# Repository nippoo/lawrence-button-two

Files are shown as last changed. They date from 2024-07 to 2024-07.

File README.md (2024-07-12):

# Lawrence Button Two

This repository contains the STL files, KiCad design and Gerber files, and Arduino code used in building the Lawrence Button Two. Unlike the first button (a custom STM32-based audio player) the electronics are a simpler, through-hole-only design.

button_back

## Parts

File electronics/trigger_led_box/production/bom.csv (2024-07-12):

Designator | Footprint | Quantity | Value | LCSC Part #
A1, A2 | Arduino_Nano | 2 | Arduino_Nano_v3.x
C1, C2 | C_Rect_L7.0mm_W2.5mm_P5.00mm | 2 | 100nF
C3 | C_Rect_L7.0mm_W2.5mm_P5.00mm | 1 | 10uF
C4, C5, C6 | CP_Radial_D10.0mm_P5.00mm | 3 | 1000uF
D1 | LED_D3.0mm_Horizontal_O1.27mm_Z10.0mm | 1 | LED
J1 | Lumberg-0105-05 | 1 | Lumberg 0105-05
J2, J3 | TerminalBlock_Phoenix_PT-1,5-2-5.0-H_1x02_P5.00mm_Horizontal | 2 | Screw_Terminal_01x02
J4 | Jack_XLR_Neutrik_NC5MAH_Horizontal | 1 | NC5MAH
J6 | Jack_XLR_Neutrik_NC5FAH_Horizontal | 1 | NC5FAH
J7 | TerminalBlock_Phoenix_PT-1,5-9-5.0-H_1x09_P5.00mm_Horizontal | 1 | Screw_Terminal_01x09
PS1 | Converter_DCDC_Murata_MEE1SxxxxSC_THT | 1 | MEE1S0505SC
R1, R2 | R_Axial_DIN0207_L6.3mm_D2.5mm_P10.16mm_Horizontal | 2 | 220R | C22962
R3 | R_Axial_DIN0207_L6.3mm_D2.5mm_P10.16mm_Horizontal | 1 | 4k7
R4, R5, R6, R7, R8 | R_Axial_DIN0207_L6.3mm_D2.5mm_P10.16mm_Horizontal | 5 | 470R
U1 | DIP-8_W7.62mm | 1 | MAX485E
U2 | DIP-8_W7.62mm | 1 | 6N137

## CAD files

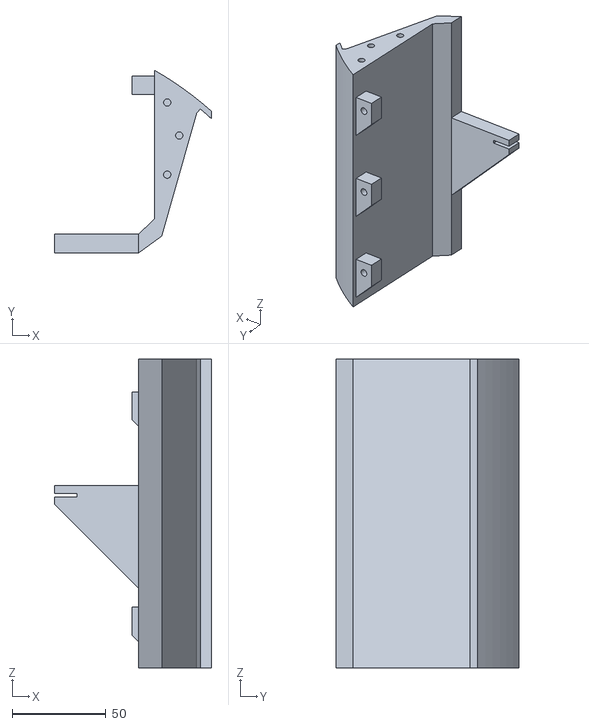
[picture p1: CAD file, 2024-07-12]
cad/left-wing.stl
83.9 x 97.5 x 165.0

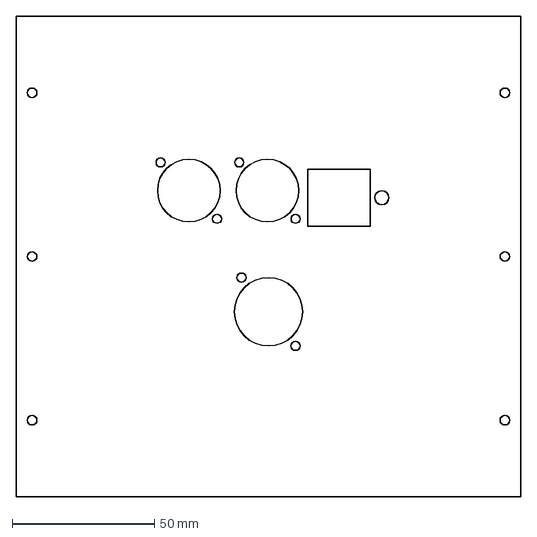
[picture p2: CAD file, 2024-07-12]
cad/frontplate.dxf
177.4 x 169.0 mm

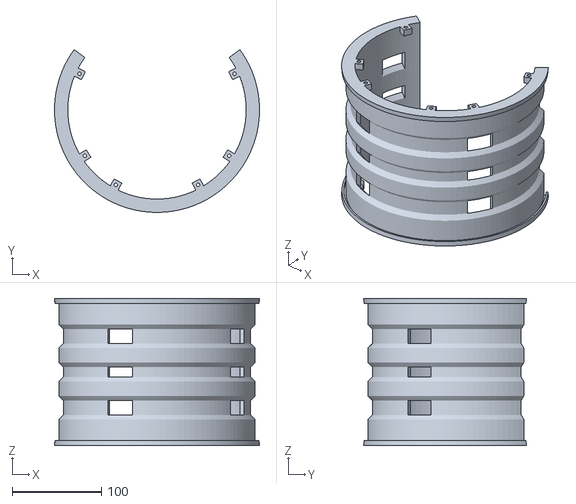
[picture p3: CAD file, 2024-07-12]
cad/middle.stl
229.9 x 182.5 x 165.0

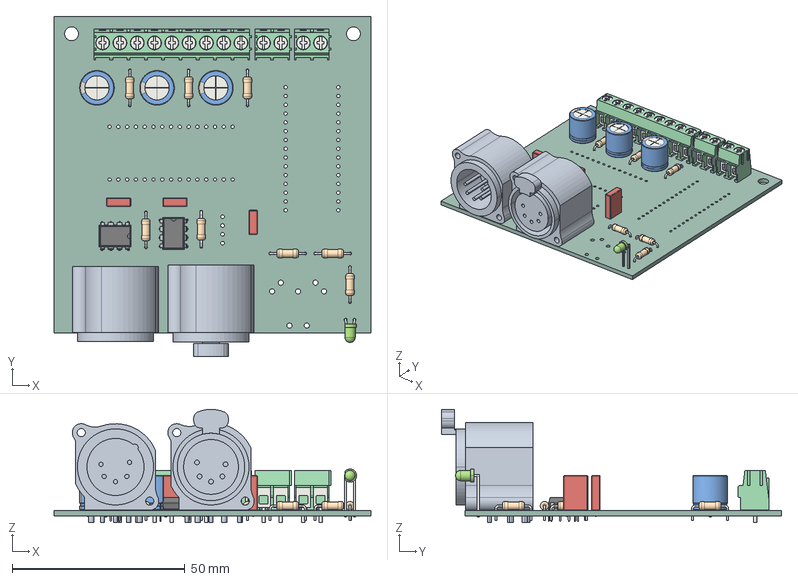
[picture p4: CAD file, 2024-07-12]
cad/trigger_led_box.step
91.5 x 98.3 x 32.7 mm
TerminalBlock_Phoenix_PT_15_2_50_H_1x02_P500mm_Horizontal x 2
R_Axial_DIN0207_L63mm_D25mm_P1016mm_Horizontal x 8
C_Rect_L70mm_W25mm_P500mm x 3
DIP-8_W7.62mm x 2
CP_Radial_D100mm_P500mm x 3
LED_D3.0mm_Horizontal_O1.27mm_Z10.0mm
NC5FAH
NC5MAH
TerminalBlock_Phoenix_PT_15_9_50_H_1x09_P500mm_Horizontal
_autosave-trigger_led_box_PCB

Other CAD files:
cad/right-wing.stl

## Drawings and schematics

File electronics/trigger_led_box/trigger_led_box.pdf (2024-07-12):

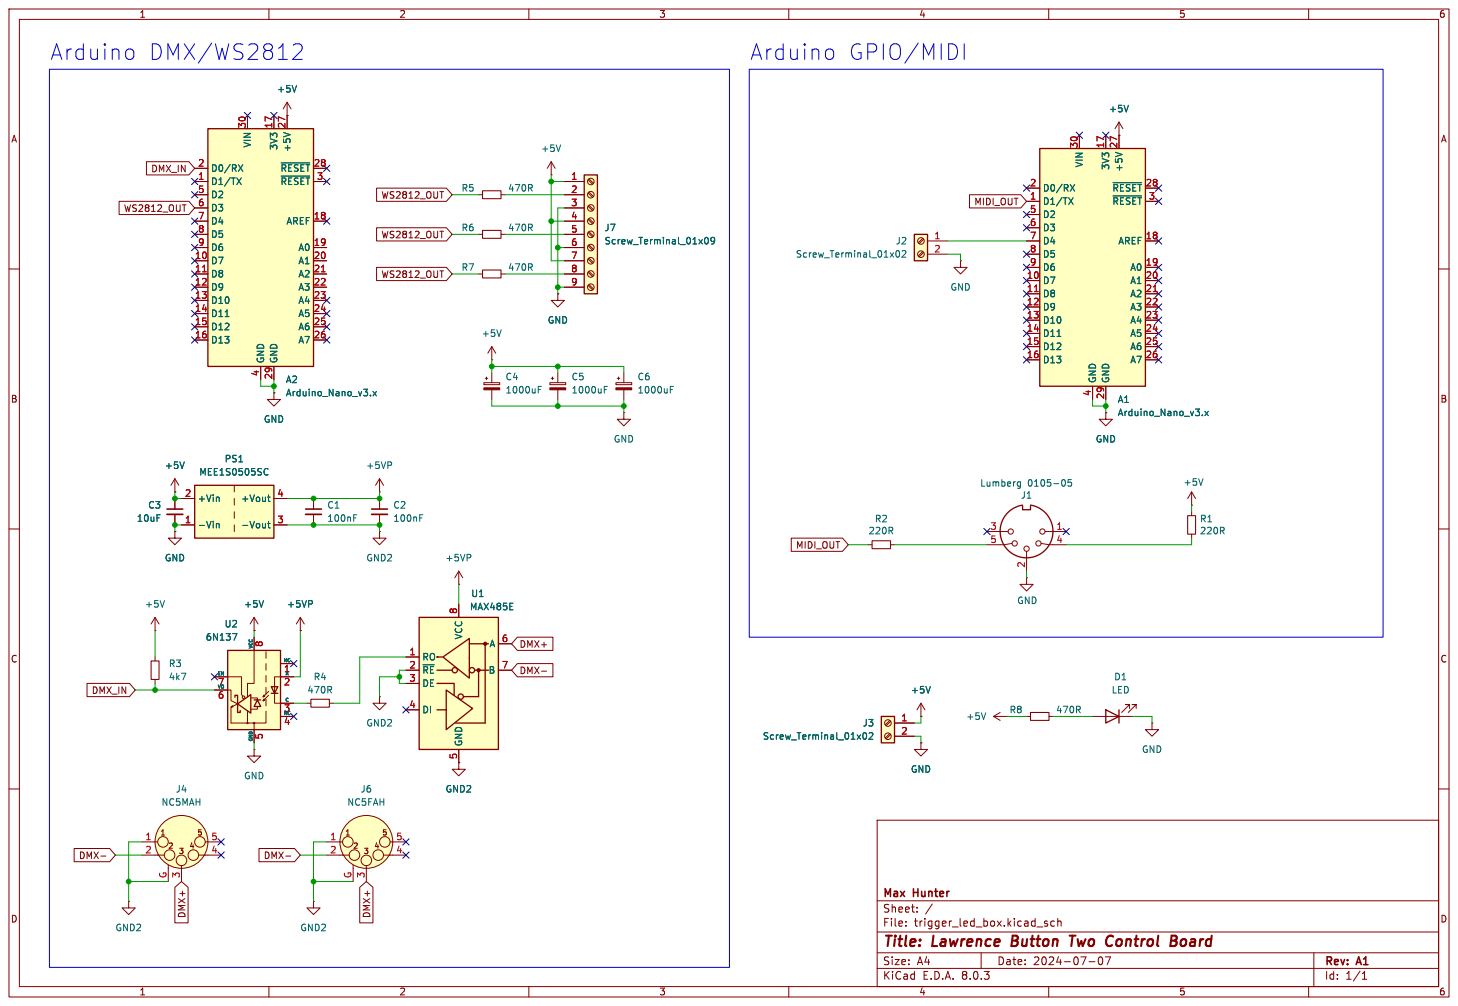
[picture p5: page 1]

Id: 1/1 Title: Lawrence Button Two Control Board

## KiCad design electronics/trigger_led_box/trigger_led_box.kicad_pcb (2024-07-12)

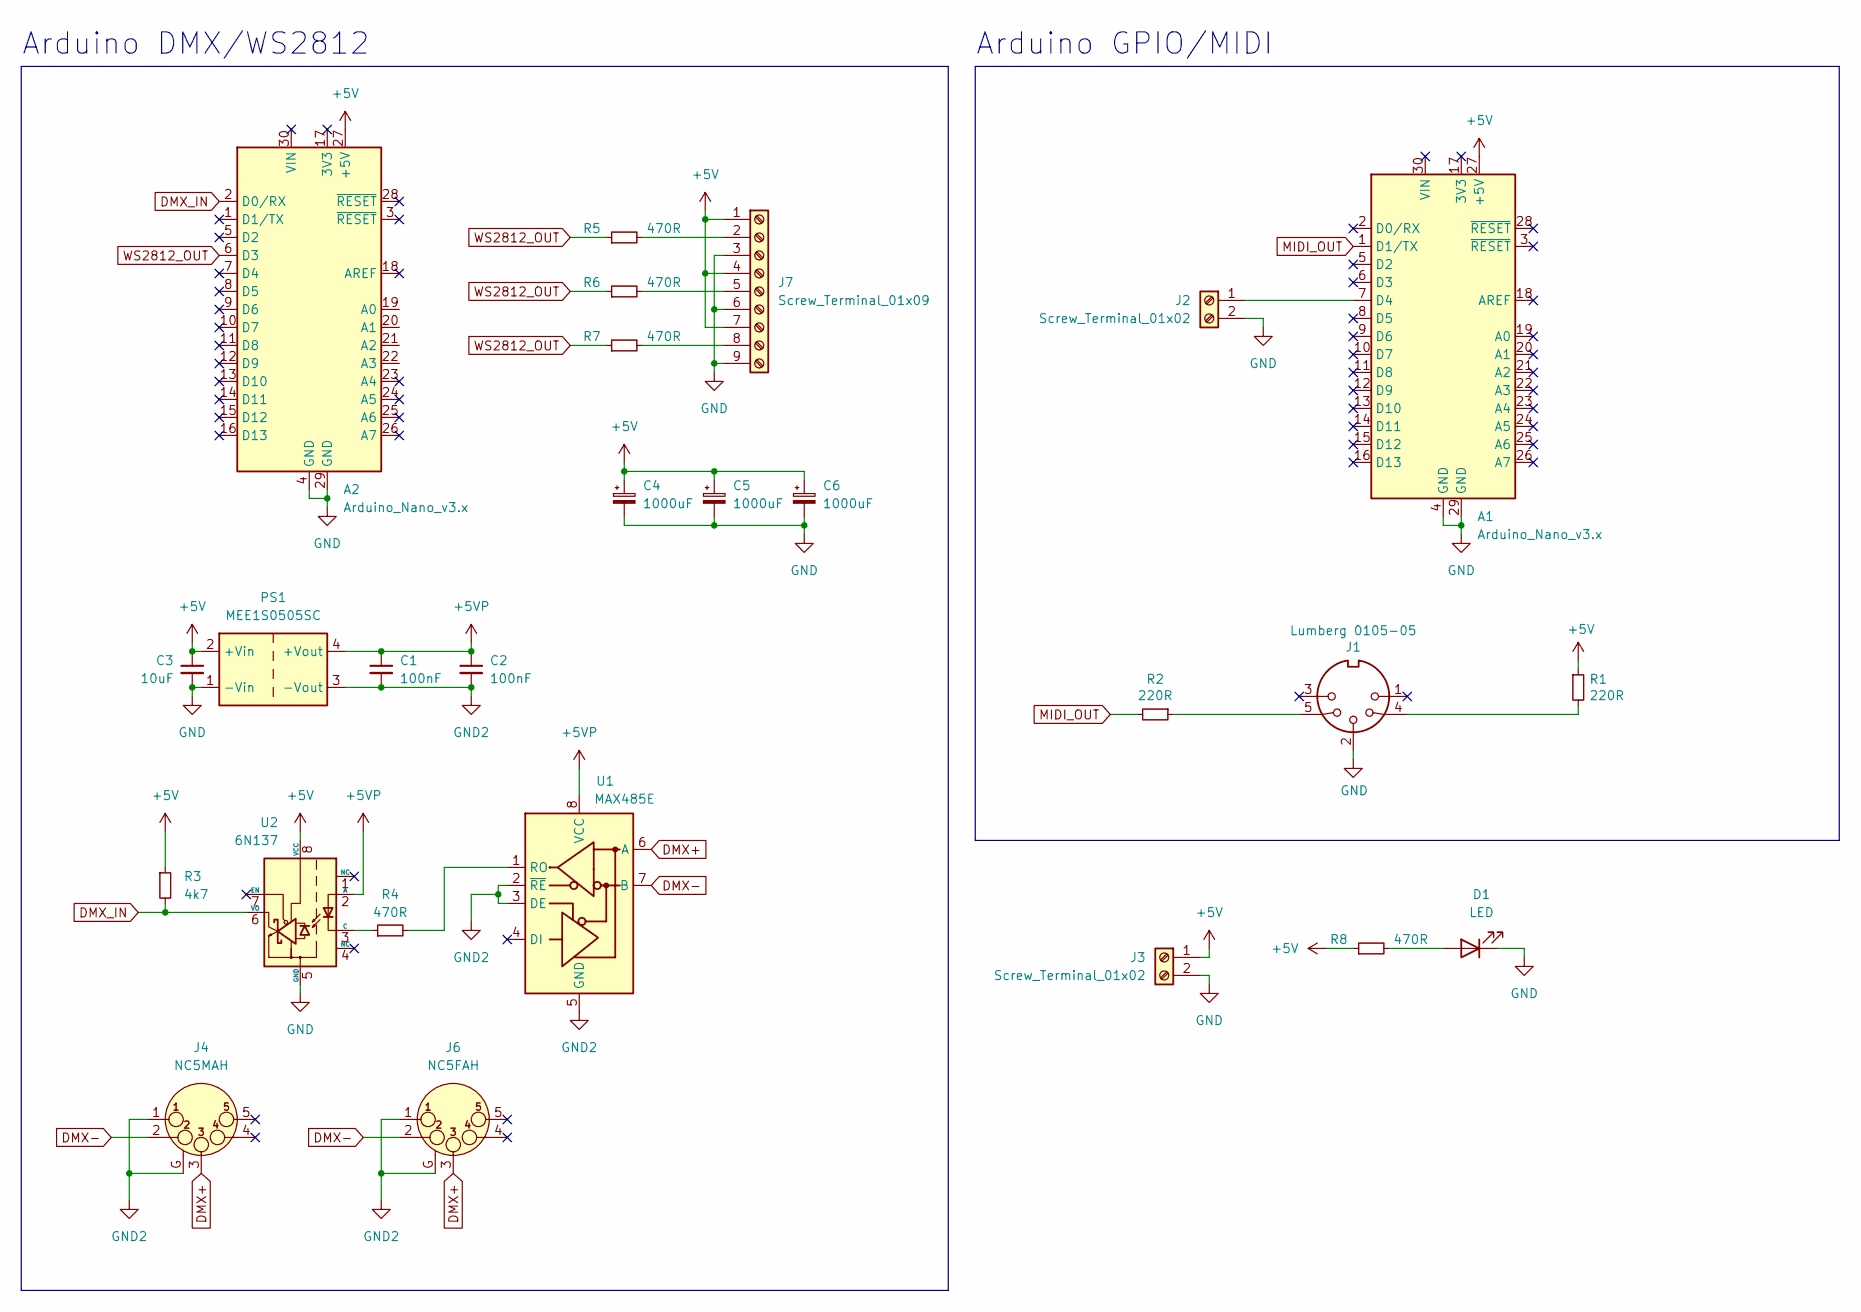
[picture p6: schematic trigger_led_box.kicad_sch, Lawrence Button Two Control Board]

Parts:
A1, A2: Arduino_Nano_v3.x; Arduino_Nano
C1, C2: 100nF; C_Rect_L7.0mm_W2.5mm_P5.00mm
C3: 10uF; C_Rect_L7.0mm_W2.5mm_P5.00mm
C4, C5, C6: 1000uF; CP_Radial_D10.0mm_P5.00mm
D1: LED; LED_D3.0mm_Horizontal_O1.27mm_Z10.0mm
J1: Lumberg 0105-05; Lumberg-0105-05
J2, J3: Screw_Terminal_01x02; TerminalBlock_Phoenix_PT-1,5-2-5.0-H_1x02_P5.00mm_Horizontal
J4: NC5MAH; Jack_XLR_Neutrik_NC5MAH_Horizontal
J6: NC5FAH; Jack_XLR_Neutrik_NC5FAH_Horizontal
J7: Screw_Terminal_01x09; TerminalBlock_Phoenix_PT-1,5-9-5.0-H_1x09_P5.00mm_Horizontal
PS1: MEE1S0505SC; Converter_DCDC_Murata_MEE1SxxxxSC_THT
R1, R2: 220R; R_Axial_DIN0207_L6.3mm_D2.5mm_P10.16mm_Horizontal; LCSC C22962
R3: 4k7; R_Axial_DIN0207_L6.3mm_D2.5mm_P10.16mm_Horizontal
R4, R5, R6, R7, R8: 470R; R_Axial_DIN0207_L6.3mm_D2.5mm_P10.16mm_Horizontal
U1: MAX485E; DIP-8_W7.62mm
U2: 6N137; DIP-8_W7.62mm

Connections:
+5V: A1.27 (+5V), A2.27 (+5V), C3.1, C4.1, C5.1, C6.1, J3.1, J7.1, J7.4, J7.7, PS1.2 (+Vin), R1.1, R3.1, R8.1, U2.8 (VCC)
+5VP: C1.1, C2.1, PS1.4 (+Vout), U1.8 (VCC), U2.2 (A)
DMX+: J4.3, J6.3, U1.6 (A)
DMX-: J4.2, J6.2, U1.7 (B)
DMX_IN: A2.2 (D0/RX), R3.2, U2.6 (VO)
GND: A1.4 (GND), A1.29 (GND), A2.4 (GND), A2.29 (GND), C3.2, C4.2, C5.2, C6.2, D1.1 (K), J1.2, J2.2, J3.2, J7.3, J7.6, J7.9, PS1.1 (-Vin), U2.5 (GND)
GND2: C1.2, C2.2, J4.1, J4.G, J6.1, J6.G, PS1.3 (-Vout), U1.2 (~RE), U1.3 (DE), U1.5 (GND)
MIDI_OUT: A1.1 (D1/TX), R2.2
unnamed: A1.7 (D4), J2.1
unnamed: D1.2 (A), R8.2
unnamed: J1.4, R1.2
unnamed: J1.5, R2.1
unnamed: J7.2, R5.2
unnamed: J7.5, R6.2
unnamed: J7.8, R7.2
unnamed: R4.2, U1.1 (RO)
unnamed: R4.1, U2.3 (C)
WS2812_OUT: A2.6 (D3), R5.1, R6.1, R7.1

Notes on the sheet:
Arduino GPIO/MIDI
Arduino DMX/WS2812

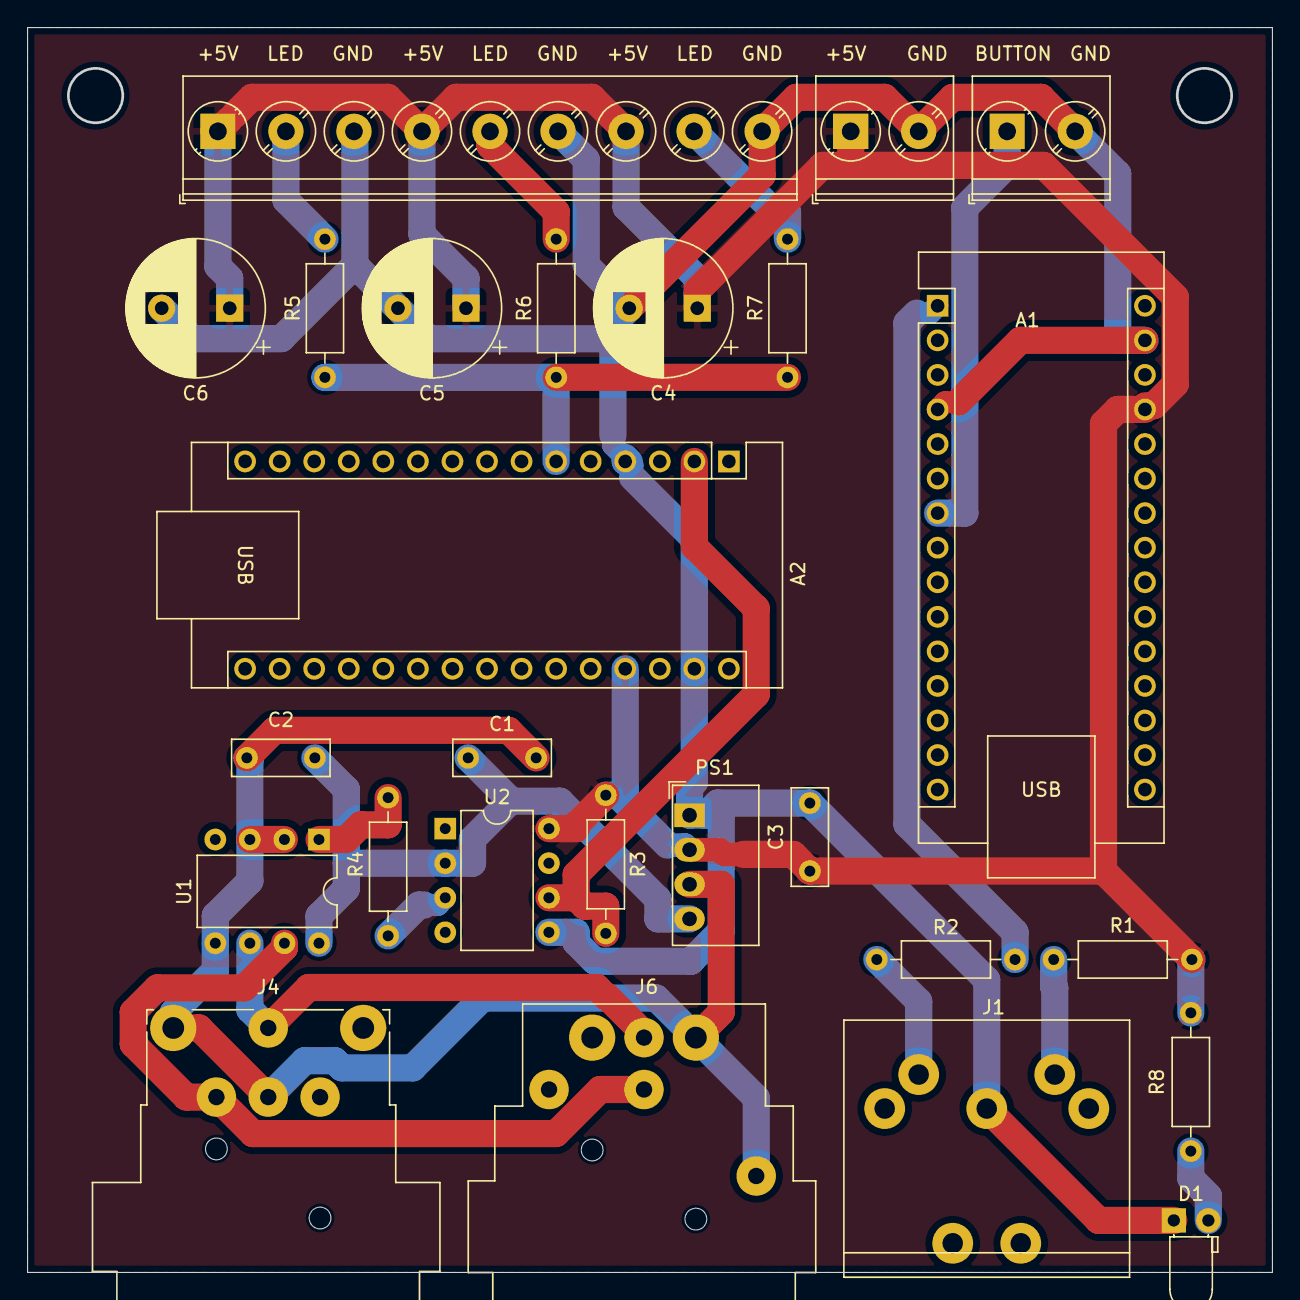
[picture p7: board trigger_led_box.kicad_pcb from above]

Board: 2 copper layers, 91.5 x 91.5 mm, 26 parts (0 on the bottom side), 18 nets.

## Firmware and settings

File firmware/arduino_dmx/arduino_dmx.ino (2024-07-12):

// Lawrence Button Two Arduino DMX to WS2812 code
// Max Hunter, 2024

#include <DMXSerial.h>
#include <FastLED.h>

#define DMX_START_CHANNEL 510
#define NUM_LEDS 256

CRGB leds[NUM_LEDS];

void setup(void) {
  DMXSerial.init(DMXProbe);
  FastLED.addLeds<NEOPIXEL, 3>(leds, NUM_LEDS);
}

void loop() {
  if (DMXSerial.receive()) {
    uint8_t red = DMXSerial.read(DMX_START_CHANNEL);
    uint8_t green = DMXSerial.read(DMX_START_CHANNEL + 1);
    uint8_t blue = DMXSerial.read(DMX_START_CHANNEL + 2);

    for (int i = 0; i < NUM_LEDS; i++) {
      leds[i].setRGB(red, green, blue);
    }
    FastLED.show();
  }
  // } else {
  //   leds[0].setRGB(((millis() % 1000) < 200) * 50, 0, 0);  // debug: we are not getting DMX
  //   FastLED.show();
  // }
}

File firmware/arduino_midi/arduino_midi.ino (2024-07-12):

// Lawrence Button Two Arduino GPIO to MIDI code
// Max Hunter, 2024

#define NOTEOFF_MSG 128

#define MIDI_NOTE 84 // C5
#define MIDI_VELOCITY 127
#define SEND_NOTE_OFF 1 // set to 0 to just send noteons
#define DEBOUNCE_DELAY 50 // milliseconds

const int buttonPin = 4;

int midi_state = 0;        // are we currently mid-note?
int button_state = 0;      // the current reading from the input pin
int last_button_state = 0; // the previous reading 

unsigned long last_debounce_time = 0;  // the last time the output pin was toggled

void setup() {
  // Set MIDI baud rate
  Serial.begin(31250);
  pinMode(buttonPin, INPUT_PULLUP);
}

void loop() {
  int reading = digitalRead(buttonPin);

  if ((reading == 0) && (button_state == 1)) {
    // send MIDI noteon
      MIDImessage(144, MIDI_NOTE, MIDI_VELOCITY);

      button_state = 0;
    // reset the debouncing timer
    // last_debounce_time = millis();
    delay(DEBOUNCE_DELAY);
  }
  else if ((reading == 1) && (button_state == 0)) {
    // send MIDI noteoff
      MIDImessage(128, MIDI_NOTE, MIDI_VELOCITY);

      button_state = 1;
    // reset the debouncing timer
    // last_debounce_time = millis();
      delay(DEBOUNCE_DELAY);

  }
}

//send MIDI message
void MIDImessage(int command, int MIDInote, int MIDIvelocity) {
  Serial.write(command);//send note on or note off command 
  Serial.write(MIDInote);//send pitch data
  Serial.write(MIDIvelocity);//send velocity data
}
